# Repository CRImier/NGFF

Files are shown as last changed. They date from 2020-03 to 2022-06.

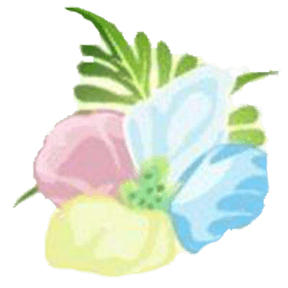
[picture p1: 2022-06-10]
docs/qitas.png

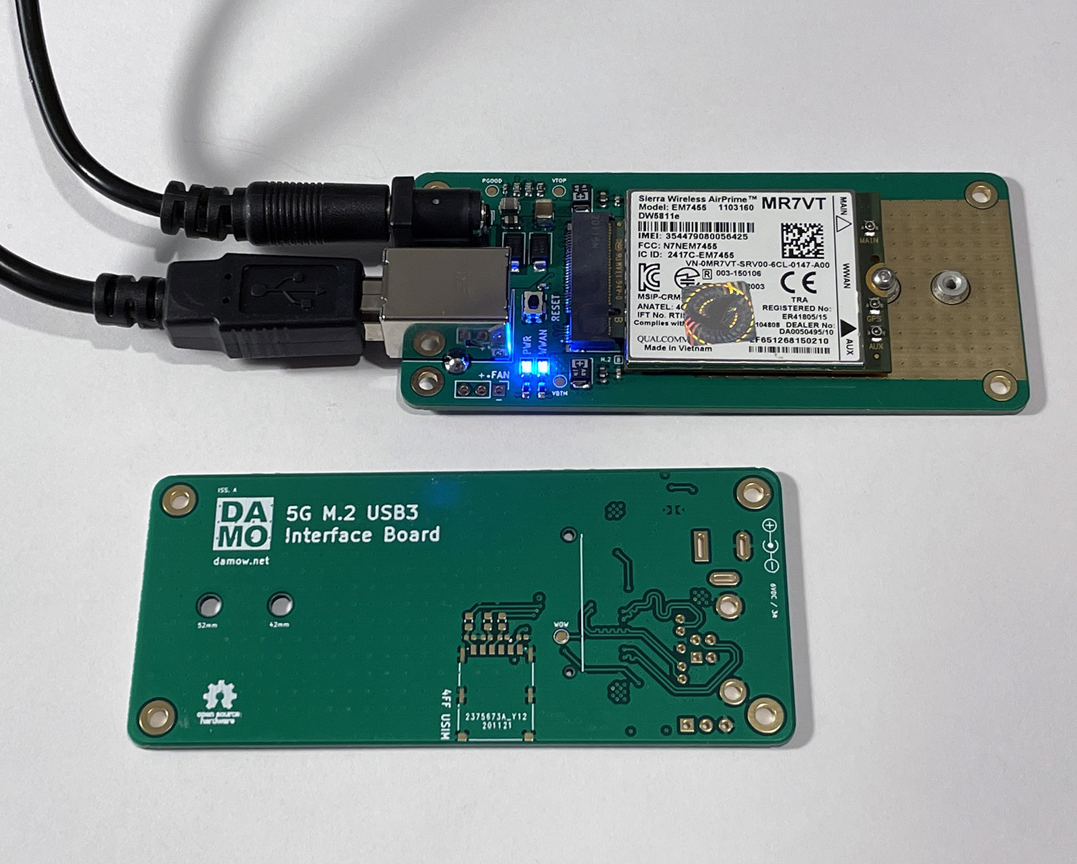
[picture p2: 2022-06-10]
project/images/board-top-bottom.jpg

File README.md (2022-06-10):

# [NGFF](https://github.com/sto-pi/NGFF)

sites (https://www.stops.top)



### [NGFF简介](https://github.com/sto-pi/NGFF)

[NGFF](https://github.com/sto-pi/NGFF) (Next Generation Form Factor)，与 NGFF 并列的是 2.5"（2.5”硬盘（包括HDD和SSD）厚度一般为9.5mm和7mm），NGFF现在已经改名为M.2，M.2有SATA 和PCIe两种总线标准。

M.2接口是一种新的主机接口方案，可以兼容多种通信协议，如sata、PCIe、USB、HSIC、UART、SMBus等。

M.2接口是为超极本（Ultrabook）量身定做的新一代接口标准，以取代原来的mSATA接口。无论是更小巧的规格尺寸，还是更高的传输性能，M.2都远胜于mSATA。

M.2接口，是Intel推出的一种替代MSATA新的接口规范。其实，对于桌面台式机用户来讲，SATA接口已经足以满足大部分用户的需求了，不过考虑到超极本用户的存储需求，Intel才急切的推出了这种新的接口标准。所以，我们在华硕、技嘉、微星等发布的新的9系列主板上都看到了这种新的M.2接口，现已普及。 [1]
与MSATA相比，M.2主要有两个方面的优势。第一是速度方面的优势。M.2接口有两种类型：Socket 2（B key——ngff）和Socket 3（M key——nvme），其中Socket2支持SATA、PCI-E X2接口，而如果采用PCI-E ×2接口标准，最大的读取速度可以达到700MB/s，写入也能达到550MB/s。而其中的Socket 3可支持PCI-E ×4接口，理论带宽可达4GB/s。

第二个是体积方面的优势。虽然，MSATA的固态硬盘体积已经足够小了，但相比M.2接口的固态硬盘，MSATA仍然没有任何优势可言。M.2标准的SSD同mSATA一样可以进行单面NAND闪存颗粒的布置，也可以进行双面布置，其中单面布置的总厚度仅有2.75mm，而双面布置的厚度也仅为3.85mm。而mSATA在体积上的劣势就明显的多，51mm×30mm的尺寸让mSATA在面积上不占优势，而4.85mm的单面布置厚度跟M.2比起来也显得厚了太多。另外，即使在大小相同的情况下，M.2也可以提供更高的存储容量。

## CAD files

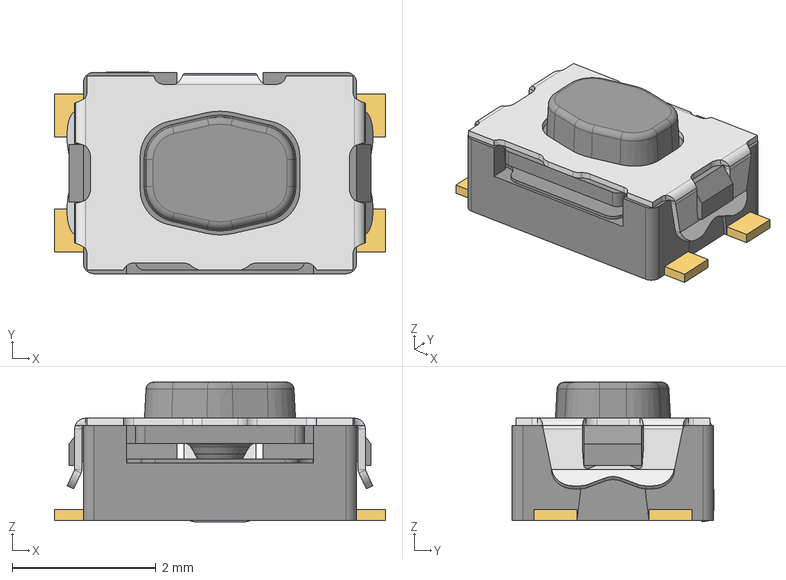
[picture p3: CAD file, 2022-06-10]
project/3d/C&K_-_KMR221GLFS.step
4.60 x 2.80 x 1.94 mm

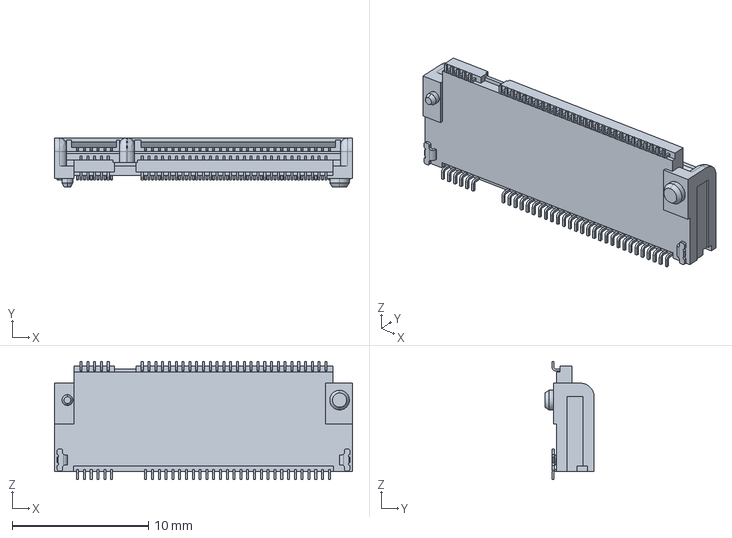
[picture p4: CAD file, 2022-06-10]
project/3d/c-2199119-3-c-3d.stp
21.9 x 3.62 x 8.70 mm

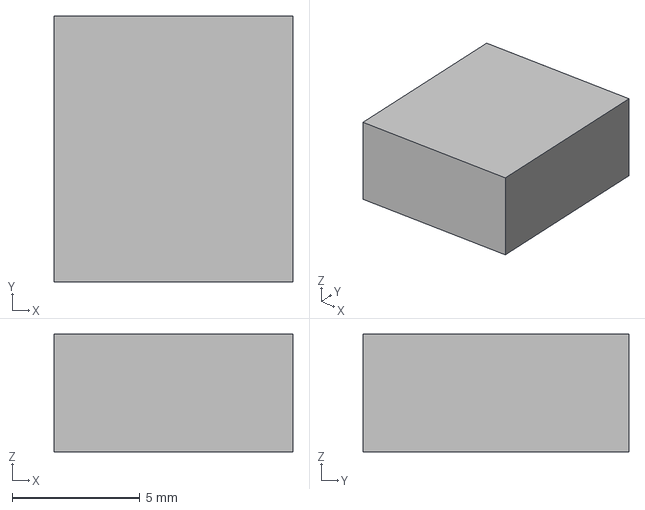
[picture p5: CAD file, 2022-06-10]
project/3d/STMicroelectronics_-_LD1085D2T33R.step
9.35 x 10.4 x 4.60 mm

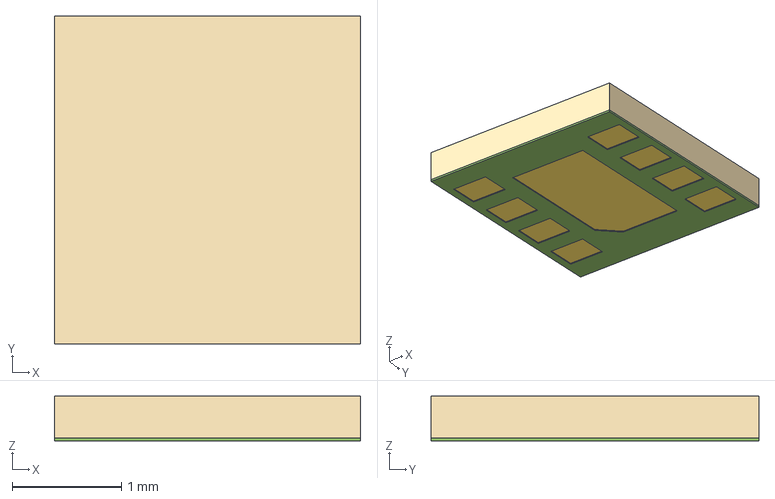
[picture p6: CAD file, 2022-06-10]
project/3d/Texas_Instruments_-_TPS82130SILR.step
2.80 x 3.00 x 0.41 mm

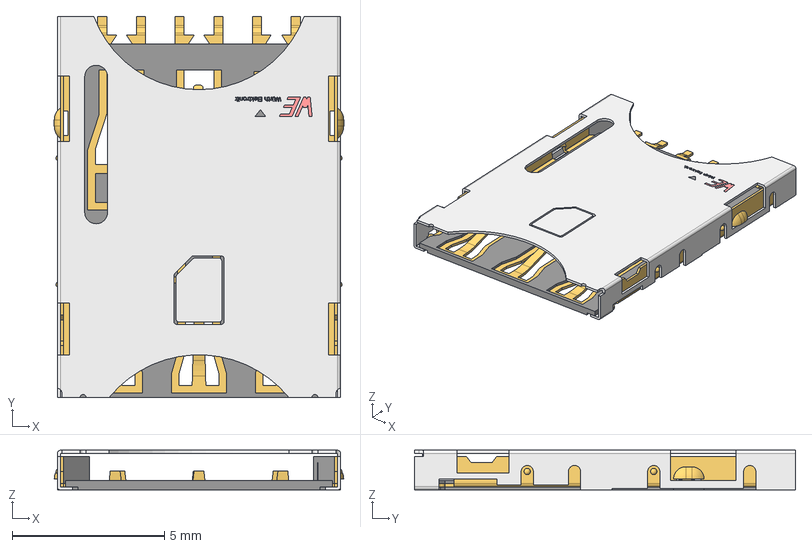
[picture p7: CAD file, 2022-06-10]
project/3d/Wurth_-_693043020611.step
9.50 x 12.5 x 1.30 mm

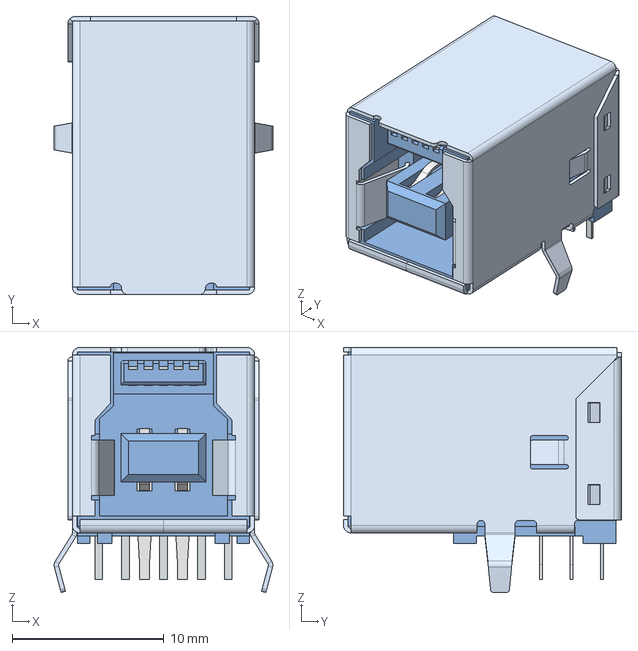
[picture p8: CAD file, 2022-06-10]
project/3d/Wurth_-_692221030100.step
14.4 x 18.3 x 16.1 mm

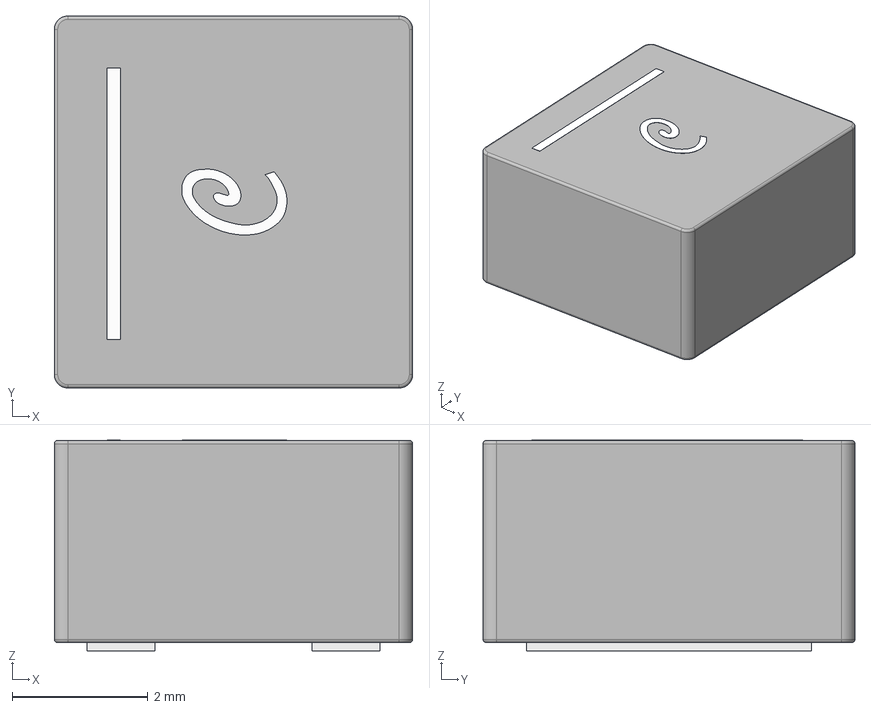
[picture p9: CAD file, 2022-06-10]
project/3d/Coilcraft_-_XAL5030-222MEB.step
5.28 x 5.48 x 3.10 mm
terminals
logo

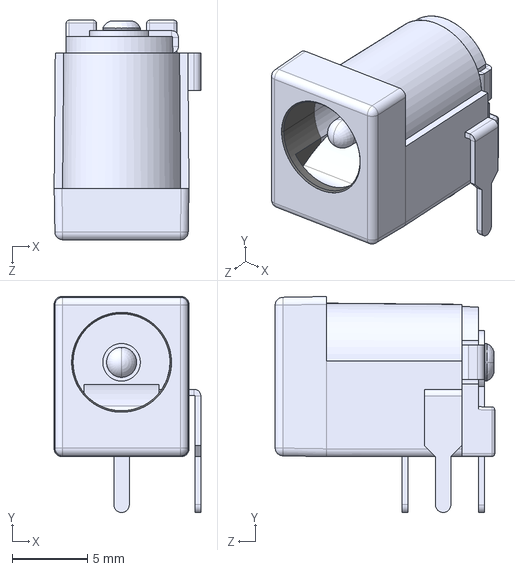
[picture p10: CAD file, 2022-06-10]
project/3d/DC Power Jack 5.5mm x 2.1mm.IGS
9.77 x 14.4 x 14.6 mm

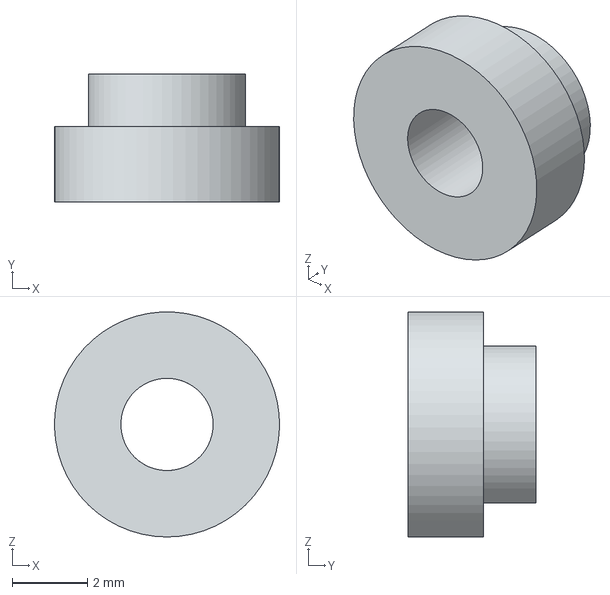
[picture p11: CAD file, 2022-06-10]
project/3d/9774020360R-Standoff.stp
6.00 x 3.40 x 6.00 mm

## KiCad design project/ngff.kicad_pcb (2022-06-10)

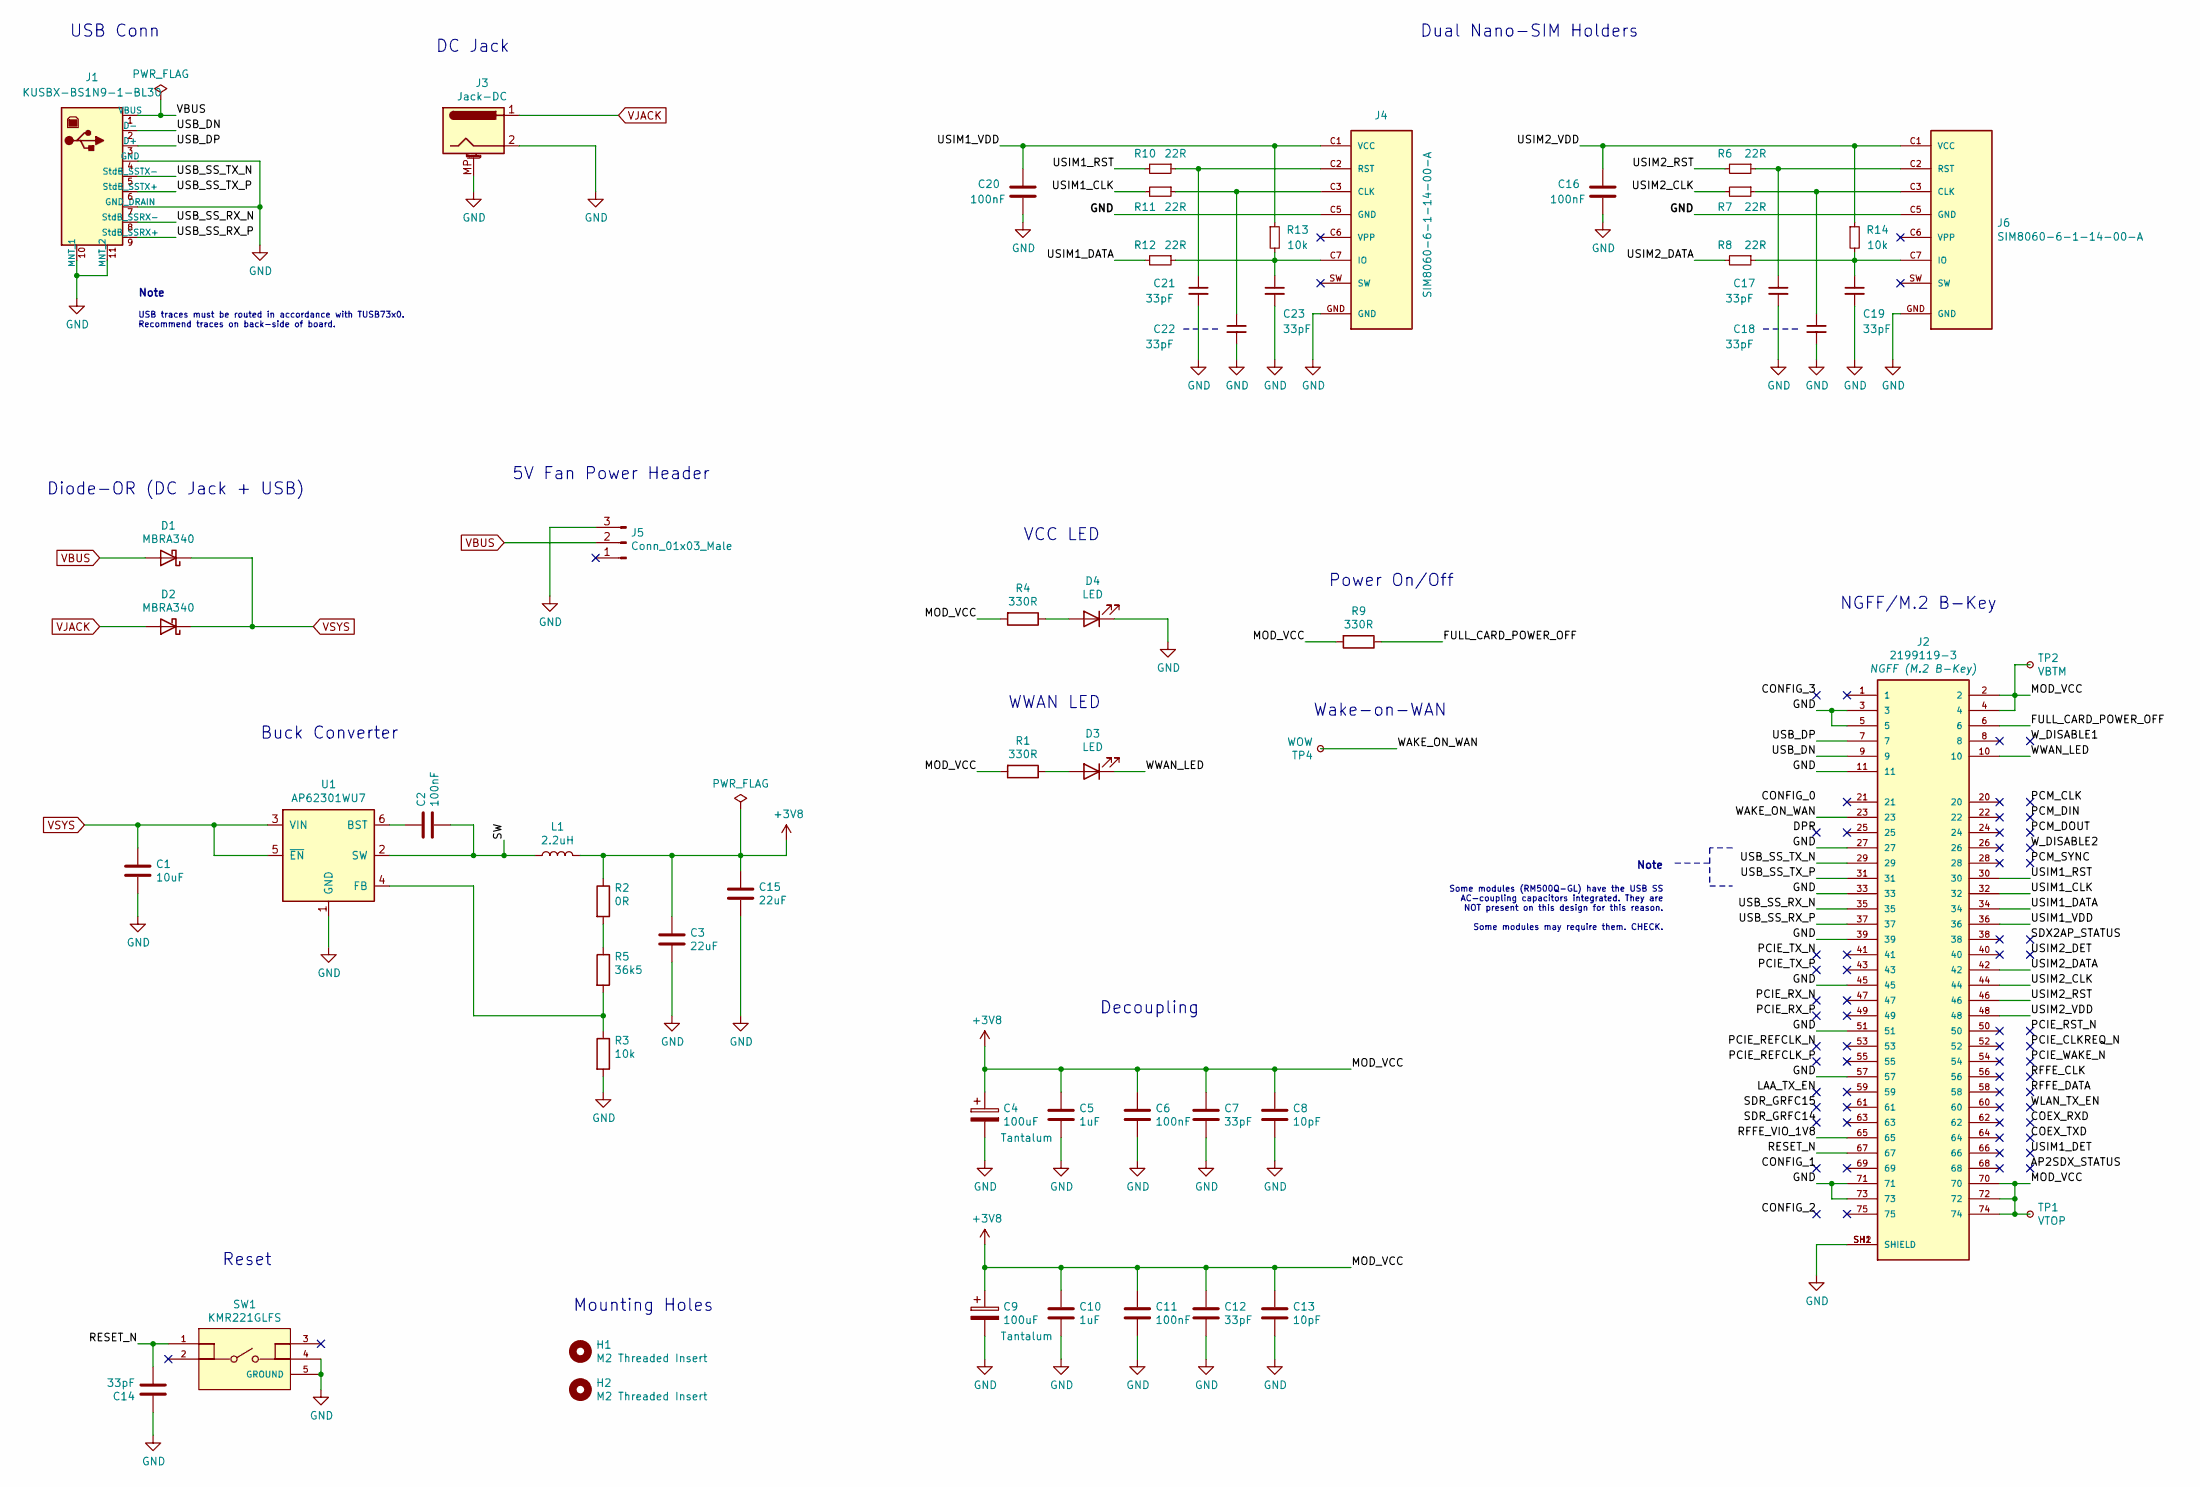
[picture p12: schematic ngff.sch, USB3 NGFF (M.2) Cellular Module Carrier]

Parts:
C1: 10uF; C_0805_2012Metric; MPN GRM21BR71A106KA73K
C2, C6, C11, C16, C20: 100nF; C_0603_1608Metric; MPN C0603C104K3RAC
C3, C15: 22uF; C_1210_3225Metric; MPN CL32B226MOJNNNE
C4, C9: 100uF; CP_EIA-3528-21_Kemet-B; MPN TCJB107M006R0040
C5, C10: 1uF; C_0603_1608Metric; MPN CGA3E1X7R1C105K080AC
C7, C12, C14, C17, C18, C19, C21, C22, C23: 33pF; C_0603_1608Metric; MPN 06035A330KAT2A
C8, C13: 10pF; C_0603_1608Metric; MPN 06035A100JAT4A
D1, D2: MBRA340; D_SMA; MPN MBRA340T3G
D3, D4: LED; LED_0805_2012Metric; MPN APTD2012LQBC/D
H1, H2: M2 Threaded Insert; 9774015243RStandoff; MPN 9774015243R
J1: KUSBX-BS1N9-1-BL30; Wurth-692221030100-0-0-MFG; MPN KUSBX-BS1N9-1-BL30
J2: 2199119-3; TE_2199119-3; MPN 2199119-3
J3: Jack-DC; BarrelJack_Wuerth_6941xx301002; MPN 694106301002
J4, J6: SIM8060-6-1-14-00-A; GCT_SIM8060-6-1-14-00-A; MPN SIM8060-6-1-14-00-A
J5: Conn_01x03_Male; PinHeader_1x03_P2.54mm_Vertical
L1: 2.2uH; L_Coilcraft_XAL5030; MPN XAL5030-222MEC
R1, R4, R9: 330R; R_0603_1608Metric
R2: 0R; R_0603_1608Metric
R3, R13, R14: 10k; R_0603_1608Metric
R5: 36k5; R_0603_1608Metric; MPN CRCW060336K5FKEA
R6, R7, R8, R10, R11, R12: 22R; R_0603_1608Metric
SW1: KMR221GLFS; CK-KMR221GLFS-MFG; MPN KMR221GLFS
TP1: VTOP; TestPoint_Pad_D1.5mm
TP2: VBTM; TestPoint_Pad_D1.5mm
TP4: WOW; TestPoint_Pad_D1.5mm
U1: AP62301WU7; TSOT-23-6; MPN AP62301WU-7

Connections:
+3V8: C3.1, C4.1, C5.1, C6.1, C7.1, C8.1, C9.1, C10.1, C11.1, C12.1, C13.1, C15.1, J2.2, J2.4, J2.70, J2.72, J2.74, L1.2, R1.2, R2.1, R4.2, R9.2, TP1.1, TP2.1
/FULL_CARD_POWER_OFF: J2.6, R9.1
/RESET_N: C14.2, J2.67, SW1.1
/RFFE_VIO_1V8: J2.65
/SW: C2.2, L1.1, U1.2 (SW)
/USB_DN: J1.2 (D-), J2.9
/USB_DP: J1.3 (D+), J2.7
/USB_SS_RX_N: J1.8 (StdB_SSRX-), J2.35
/USB_SS_RX_P: J1.9 (StdB_SSRX+), J2.37
/USB_SS_TX_N: J1.5 (StdB_SSTX-), J2.29
/USB_SS_TX_P: J1.6 (StdB_SSTX+), J2.31
/USIM1_CLK: J2.32, R11.2
/USIM1_DATA: J2.34, R12.2
/USIM1_RST: J2.30, R10.2
/USIM1_VDD: C20.1, J2.36, J4.C1 (VCC), R13.1
/USIM2_CLK: J2.44, R7.2
/USIM2_DATA: J2.42, R8.2
/USIM2_RST: J2.46, R6.2
/USIM2_VDD: C16.1, J2.48, J6.C1 (VCC), R14.1
/WAKE_ON_WAN: J2.23, TP4.1
/WWAN_LED: D3.1 (K), J2.10
GND: C1.2, C3.2, C4.2, C5.2, C6.2, C7.2, C8.2, C9.2, C10.2, C11.2, C12.2, C13.2, C14.1, C15.2, C16.2, C17.2, C18.2, C19.2, C20.2, C21.2, C22.2, C23.2, D4.1 (K), J1.4 (GND), J1.7 (GND_DRAIN), J1.10 (MNT_1), J1.11 (MNT_2), J2.3, J2.5, J2.11, J2.27, J2.33, J2.39, J2.45, J2.51, J2.57, J2.71, J2.73, J2.SH1 (SHIELD), J2.SH2 (SHIELD), J3.2, J3.MP (MountPin), J4.C5 (GND), J4.GND, J5.3, J6.C5 (GND), J6.GND, R3.2, SW1.4, SW1.5 (GROUND), U1.1 (GND)
unnamed: C2.1, U1.6 (BST)
unnamed: C17.1, J6.C2 (RST), R6.1
unnamed: C18.1, J6.C3 (CLK), R7.1
unnamed: C19.1, J6.C7 (IO), R8.1, R14.2
unnamed: C21.1, J4.C2 (RST), R10.1
unnamed: C22.1, J4.C3 (CLK), R11.1
unnamed: C23.1, J4.C7 (IO), R12.1, R13.2
unnamed: D3.2 (A), R1.1
unnamed: D4.2 (A), R4.1
unnamed: R2.2, R5.1
unnamed: R3.1, R5.2, U1.4 (FB)
VBUS: D1.2 (A), J1.1 (VBUS), J5.2
VJACK: D2.2 (A), J3.1
VSYS: C1.1, D1.1 (K), D2.1 (K), U1.3 (VIN), U1.5 (~EN)

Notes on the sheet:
Dual Nano-SIM Holders
VCC LED
WWAN LED
Reset
5V Fan Power Header
Diode-OR (DC Jack + USB)
USB Conn
DC Jack
Power On/Off
Decoupling
NGFF/M.2 B-Key
Wake-on-WAN
Mounting Holes
Note
Some modules (RM500Q-GL) have the USB SS AC-coupling capacitors integrated. They are NOT present on this design for this reason. Some modules may require them. CHECK.
USB traces must be routed in accordance with TUSB73x0. Recommend traces on back-side of board.
Buck Converter

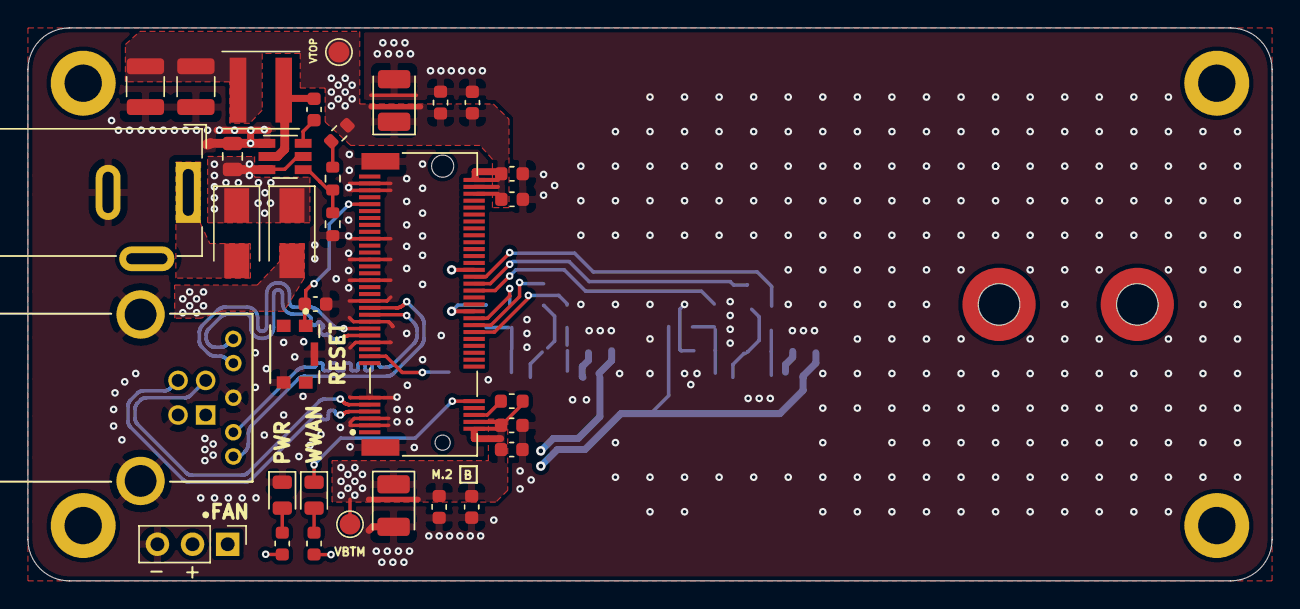
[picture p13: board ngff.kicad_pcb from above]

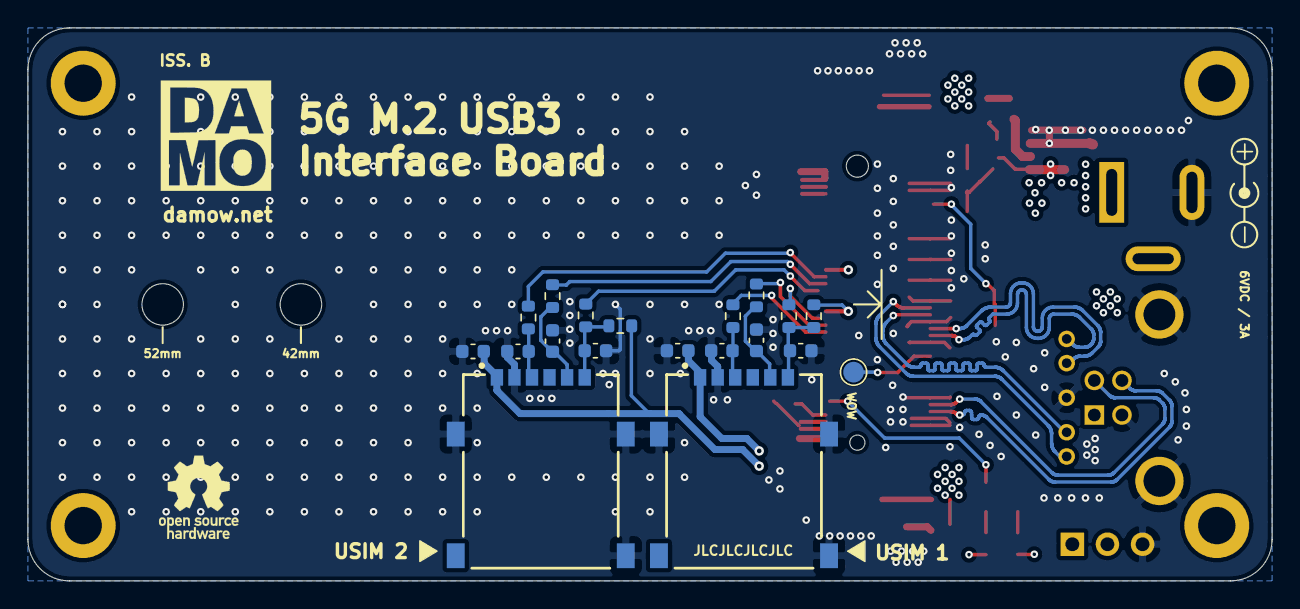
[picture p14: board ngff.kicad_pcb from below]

Board: 4 copper layers, 90.0 x 40.0 mm, 55 parts (19 on the bottom side), 35 nets.

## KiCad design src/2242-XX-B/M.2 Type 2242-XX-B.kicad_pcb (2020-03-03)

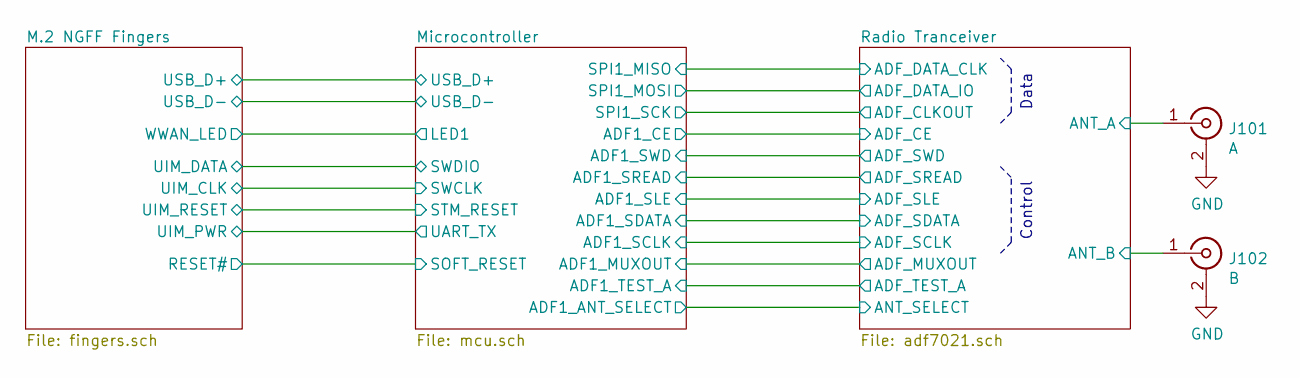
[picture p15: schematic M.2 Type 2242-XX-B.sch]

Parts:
J101: A; U.FL_Hirose_U.FL-R-SMT-1_Vertical
J102: B; U.FL_Hirose_U.FL-R-SMT-1_Vertical

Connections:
/Radio Tranceiver/ANT_A: J101.1 (In); also elsewhere on the board
/Radio Tranceiver/ANT_B: J102.1 (In); also elsewhere on the board
GND: J101.2 (Ext), J102.2 (Ext); also elsewhere on the board

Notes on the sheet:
Control
Data

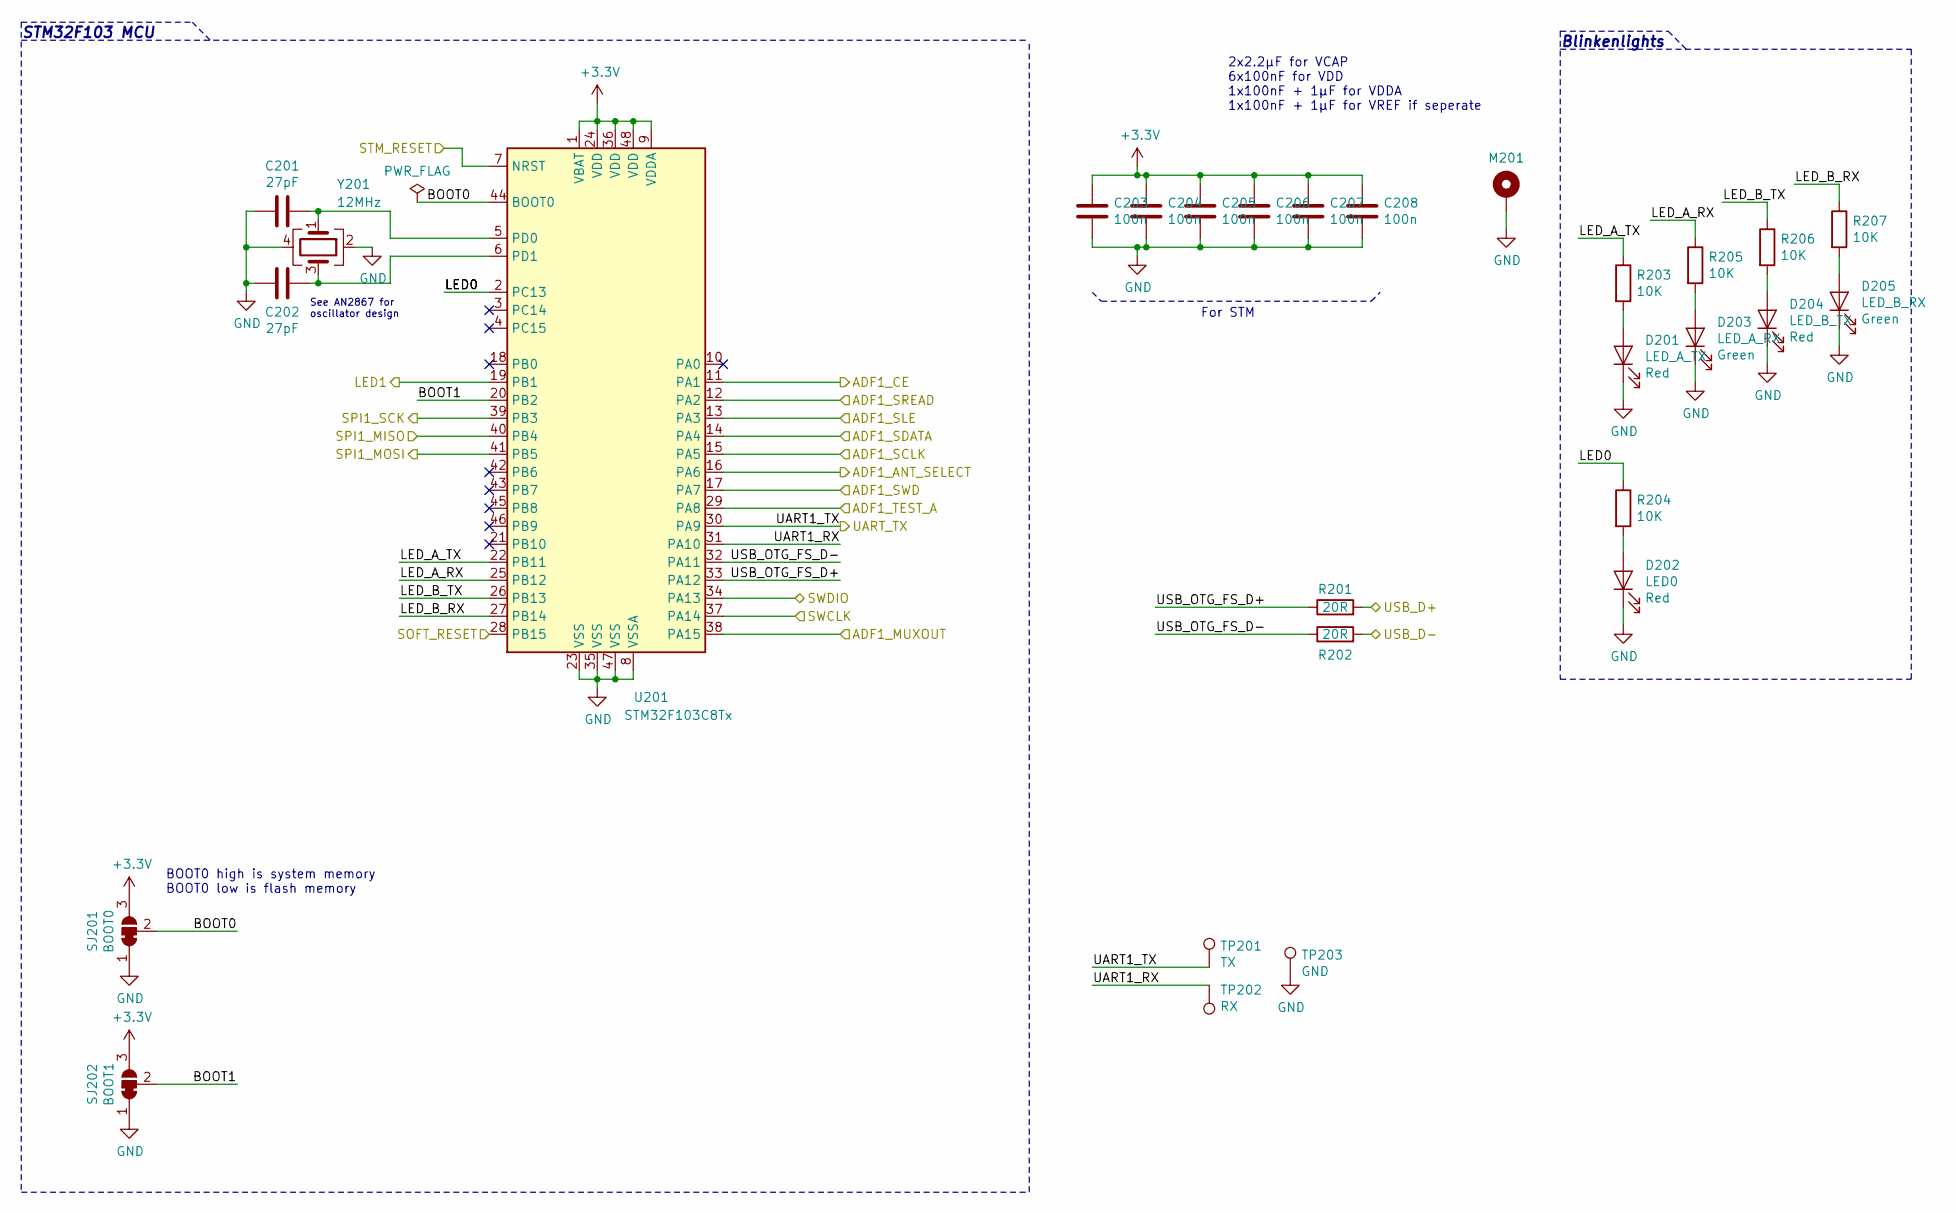
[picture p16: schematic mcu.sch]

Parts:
C201, C202: 27pF; C_0603_1608Metric
C203, C204, C205, C206, C207, C208: 100n; C_0603_1608Metric
D201: LED_A_TX; LED_0603_1608Metric
D202: LED0; LED_0603_1608Metric
D203: LED_A_RX; LED_0603_1608Metric
D204: LED_B_TX; LED_0603_1608Metric
D205: LED_B_RX; LED_0603_1608Metric
M201: MountingHole_Pad; M.2_Standoff_Card_Pad
R201, R202: 20R; R_0603_1608Metric
R203, R204, R205, R206, R207: 10K; R_0603_1608Metric
SJ201: BOOT0; SolderJumper-3_P1.3mm_Bridged12_RoundedPad1.0x1.5mm
SJ202: BOOT1; SolderJumper-3_P1.3mm_Bridged12_RoundedPad1.0x1.5mm
TP201: TX; TestPad
TP202: RX; TestPad
TP203: GND; TestPad
U201: STM32F103C8Tx; LQFP-48_7x7mm_P0.5mm
Y201: 12MHz; Crystal_SMD_3225-4Pin_3.2x2.5mm; digikey# 1923-1568-1-ND

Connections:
+3V3: C203.1, C204.1, C205.1, C206.1, C207.1, C208.1, SJ201.3 (B), SJ202.3 (B), U201.1 (VBAT), U201.9 (VDDA), U201.24 (VDD), U201.36 (VDD), U201.48 (VDD); also elsewhere on the board
/M.2 NGFF Fingers/RESET#: U201.28 (PB15); also elsewhere on the board
/M.2 NGFF Fingers/USB_D+: R201.2; also elsewhere on the board
/M.2 NGFF Fingers/USB_D-: R202.2; also elsewhere on the board
/Microcontroller/ADF1_ANT_SELECT: U201.16 (PA6); also elsewhere on the board
/Microcontroller/ADF1_CE: U201.11 (PA1); also elsewhere on the board
/Microcontroller/ADF1_MUXOUT: U201.38 (PA15); also elsewhere on the board
/Microcontroller/ADF1_SCLK: U201.15 (PA5); also elsewhere on the board
/Microcontroller/ADF1_SDATA: U201.14 (PA4); also elsewhere on the board
/Microcontroller/ADF1_SLE: U201.13 (PA3); also elsewhere on the board
/Microcontroller/ADF1_SREAD: U201.12 (PA2); also elsewhere on the board
/Microcontroller/ADF1_SWD: U201.17 (PA7); also elsewhere on the board
/Microcontroller/ADF1_TEST_A: U201.29 (PA8); also elsewhere on the board
/Microcontroller/BOOT0: SJ201.2 (C), U201.44 (BOOT0)
/Microcontroller/BOOT1: SJ202.2 (C), U201.20 (PB2)
/Microcontroller/LED0: R204.1, U201.2 (PC13)
/Microcontroller/LED1: U201.19 (PB1); also elsewhere on the board
/Microcontroller/LED_A_RX: R205.1, U201.25 (PB12)
/Microcontroller/LED_A_TX: R203.1, U201.22 (PB11)
/Microcontroller/LED_B_RX: R207.1, U201.27 (PB14)
/Microcontroller/LED_B_TX: R206.1, U201.26 (PB13)
/Microcontroller/STM_RESET: U201.7 (NRST); also elsewhere on the board
/Microcontroller/SWCLK: U201.37 (PA14); also elsewhere on the board
/Microcontroller/SWDIO: U201.34 (PA13); also elsewhere on the board
/Microcontroller/UART1_RX: TP202.1, U201.31 (PA10)
/Microcontroller/UART_TX: TP201.1, U201.30 (PA9); also elsewhere on the board
/Microcontroller/USB_OTG_FS_D+: R201.1, U201.33 (PA12)
/Microcontroller/USB_OTG_FS_D-: R202.1, U201.32 (PA11)
/Radio Tranceiver/ADF_CLKOUT: U201.39 (PB3); also elsewhere on the board
/Radio Tranceiver/ADF_DATA_CLK: U201.40 (PB4); also elsewhere on the board
/Radio Tranceiver/ADF_DATA_IO: U201.41 (PB5); also elsewhere on the board
GND: C201.2, C202.2, C203.2, C204.2, C205.2, C206.2, C207.2, C208.2, D201.1 (K), D202.1 (K), D203.1 (K), D204.1 (K), D205.1 (K), M201.1, SJ201.1 (A), SJ202.1 (A), TP203.1, U201.8 (VSSA), U201.23 (VSS), U201.35 (VSS), U201.47 (VSS), Y201.2, Y201.4; also elsewhere on the board
unnamed: C201.1, U201.5 (PD0), Y201.1
unnamed: C202.1, U201.6 (PD1), Y201.3
unnamed: D201.2 (A), R203.2
unnamed: D202.2 (A), R204.2
unnamed: D203.2 (A), R205.2
unnamed: D204.2 (A), R206.2
unnamed: D205.2 (A), R207.2

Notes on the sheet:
See AN2867 for oscillator design
STM32F103 MCU
Blinkenlights
2x2.2µF for VCAP 6x100nF for VDD 1x100nF + 1µF for VDDA 1x100nF + 1µF for VREF if seperate
For STM
BOOT0 high is system memory BOOT0 low is flash memory

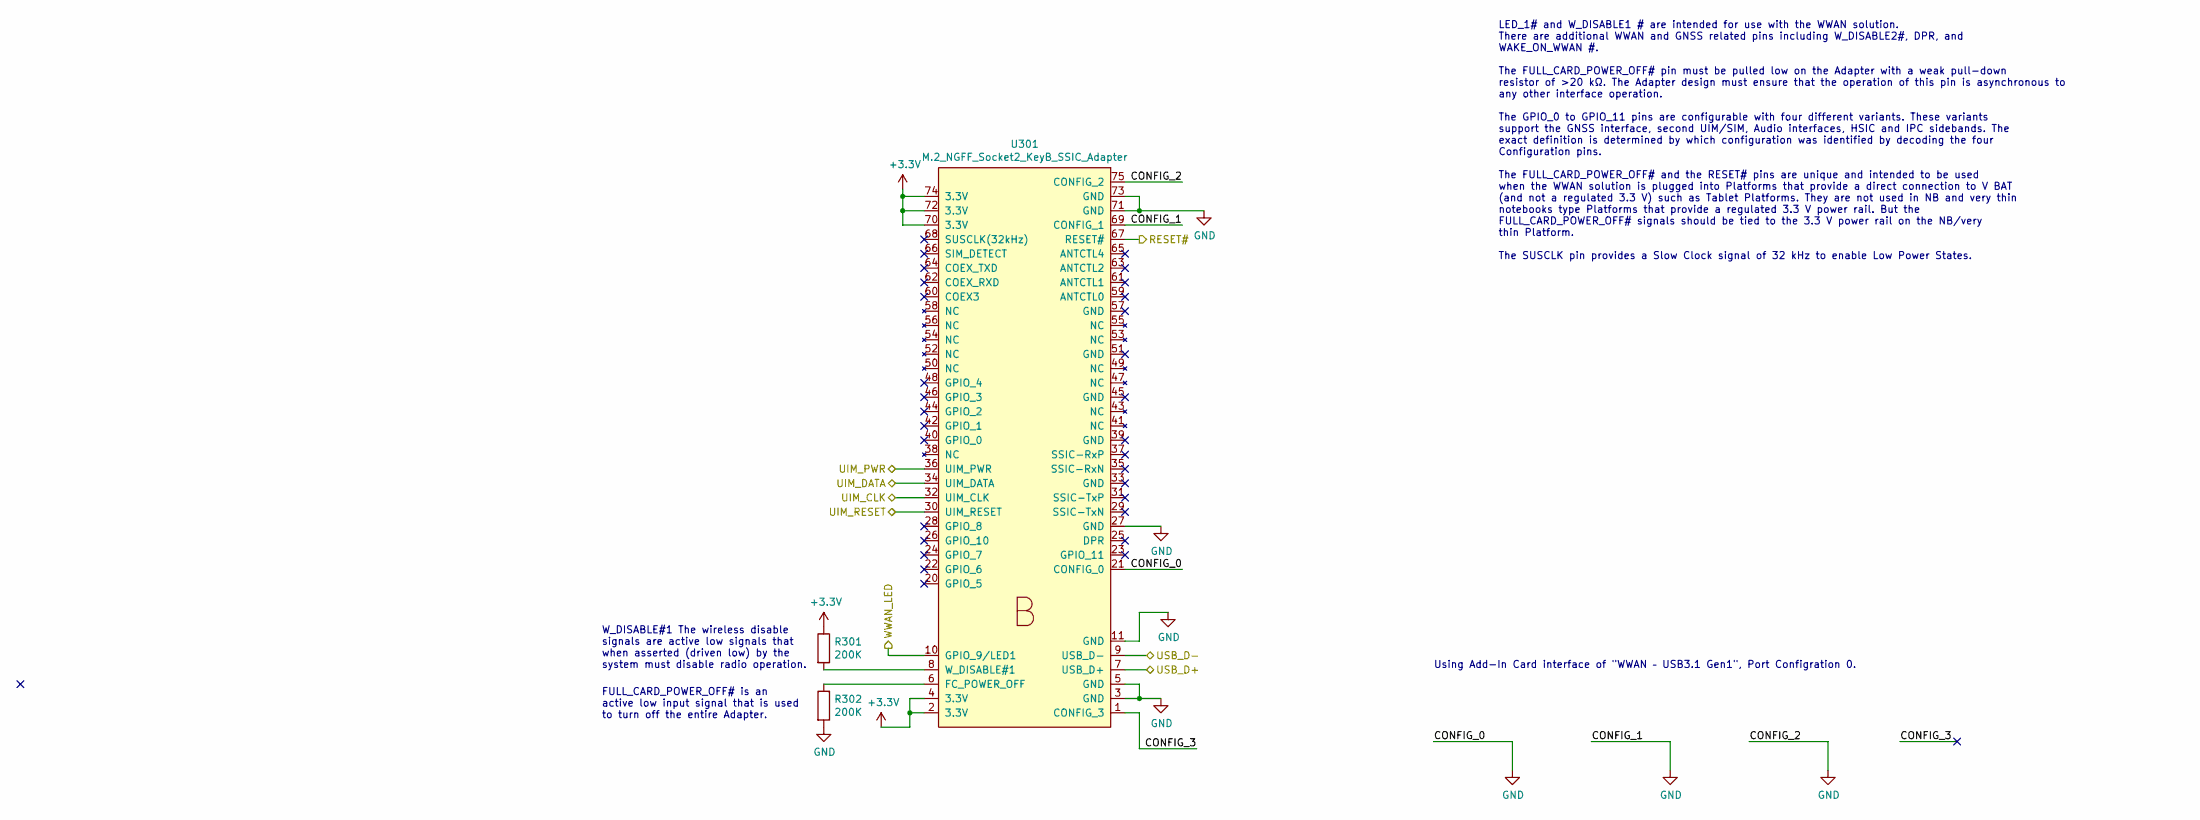
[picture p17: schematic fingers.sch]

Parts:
R301, R302: 200K; R_0603_1608Metric
U301: M.2_NGFF_Socket2_KeyB_SSIC_Adapter; M.2_Key_B_Fingers

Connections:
+3V3: R301.1, U301.2 (3.3V), U301.4 (3.3V), U301.70 (3.3V), U301.72 (3.3V), U301.74 (3.3V); also elsewhere on the board
/M.2 NGFF Fingers/CONFIG_3: U301.1 (CONFIG_3)
/M.2 NGFF Fingers/RESET#: U301.67 (RESET#); also elsewhere on the board
/M.2 NGFF Fingers/USB_D+: U301.7 (USB_D+); also elsewhere on the board
/M.2 NGFF Fingers/USB_D-: U301.9 (USB_D-); also elsewhere on the board
/Microcontroller/LED1: U301.10 (GPIO_9/LED1); also elsewhere on the board
/Microcontroller/STM_RESET: U301.30 (UIM_RESET); also elsewhere on the board
/Microcontroller/SWCLK: U301.32 (UIM_CLK); also elsewhere on the board
/Microcontroller/SWDIO: U301.34 (UIM_DATA); also elsewhere on the board
/Microcontroller/UART_TX: U301.36 (UIM_PWR); also elsewhere on the board
GND: R302.2, U301.3 (GND), U301.5 (GND), U301.11 (GND), U301.21 (CONFIG_0), U301.27 (GND), U301.69 (CONFIG_1), U301.71 (GND), U301.73 (GND), U301.75 (CONFIG_2); also elsewhere on the board
unnamed: R301.2, U301.8 (W_DISABLE#1)
unnamed: R302.1, U301.6 (FC_POWER_OFF)

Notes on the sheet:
LED_1# and W_DISABLE1 # are intended for use with the WWAN solution. There are additional WWAN and GNSS related pins including W_DISABLE2#, DPR, and WAKE_ON_WWAN #. The FULL_CARD_POWER_OFF# pin must be pulled low on the Adapter with a weak pull-down resistor of >20 kΩ. The Adapter design must ensur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
FULL_CARD_POWER_OFF# is an active low input signal that is used to turn off the entire Adapter.
W_DISABLE#1 The wireless disable signals are active low signals that when asserted (driven low) by the system must disable radio operation.
Using Add-In Card interface of "WWAN – USB3.1 Gen1", Port Configration 0.

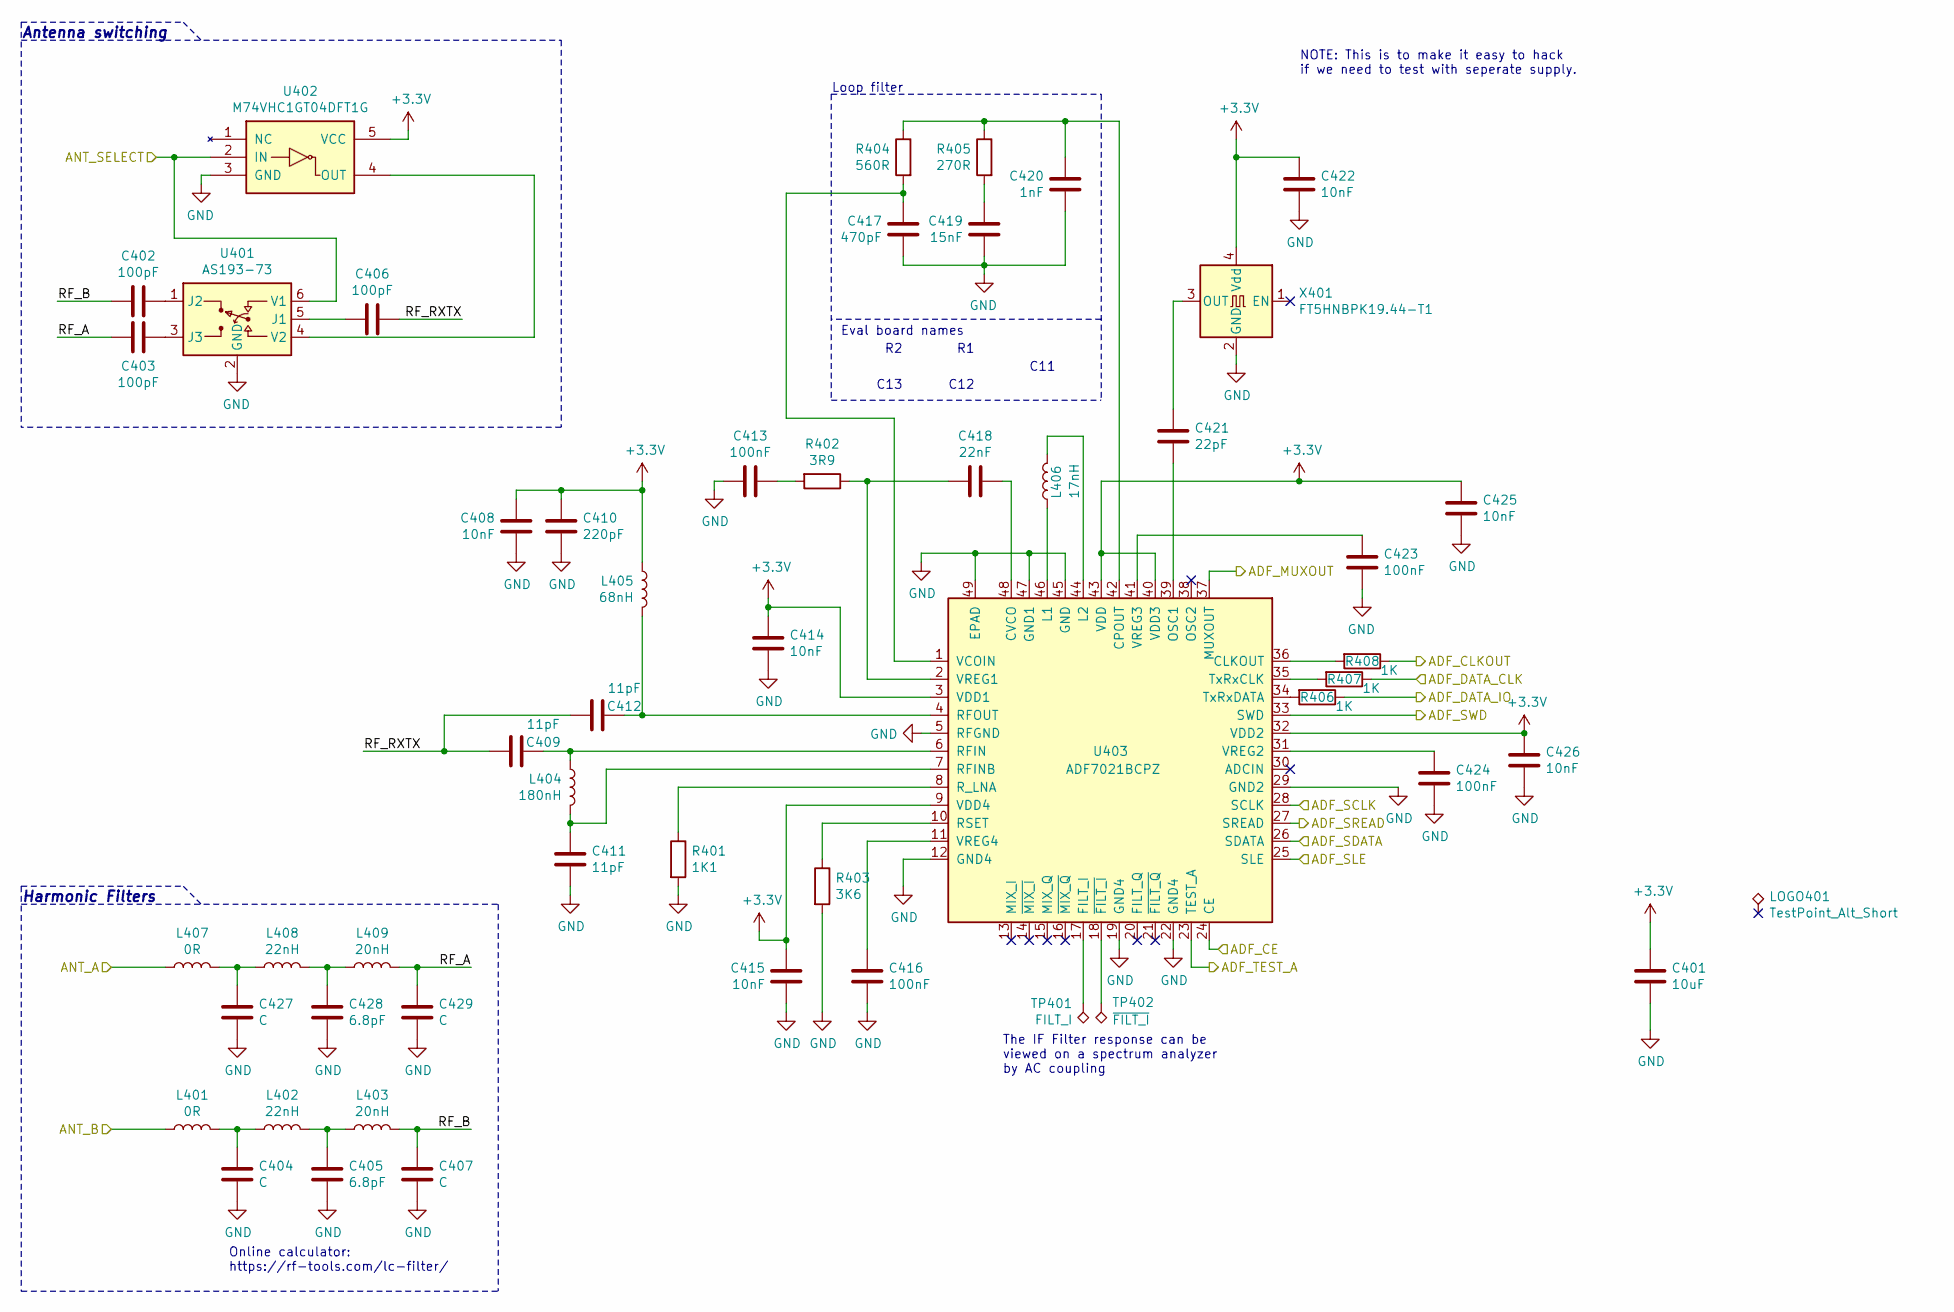
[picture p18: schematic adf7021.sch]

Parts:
C401: 10uF; C_0805_2012Metric
C402, C403, C406: 100pF; C_0603_1608Metric
C404, C407, C427, C429: C; C_0603_1608Metric
C405, C428: 6.8pF; C_0603_1608Metric
C408, C414, C415, C422, C425, C426: 10nF; C_0603_1608Metric
C409, C411, C412: 11pF; C_0603_1608Metric
C410: 220pF; C_0603_1608Metric
C413, C416, C423, C424: 100nF; C_0603_1608Metric
C417: 470pF; C_0603_1608Metric
C418: 22nF; C_0603_1608Metric
C419: 15nF; C_0603_1608Metric
C420: 1nF; C_0603_1608Metric
C421: 22pF; C_0603_1608Metric
L401, L407: 0R; L_0603_1608Metric
L402, L408: 22nH; L_0603_1608Metric
L403, L409: 20nH; L_0603_1608Metric
L404: 180nH; L_0603_1608Metric
L405: 68nH; L_0603_1608Metric
L406: 17nH; L_0603_1608Metric
LOGO401: TestPoint_Alt_Short; KiCad-Logo_Back
R401: 1K1; R_0603_1608Metric
R402: 3R9; R_0603_1608Metric
R403: 3K6; R_0603_1608Metric
R404: 560R; R_0603_1608Metric
R405: 270R; R_0603_1608Metric
R406, R407, R408: 1K; R_0603_1608Metric
TP401: FILT_I; TestPad
TP402: ~FILT_I; TestPad
U401: AS193-73; SuperSOT-6
U402: M74VHC1GT04DFT1G; SOT-353_SC-70-5; digikey# M74VHC1GT04DFT1GOSCT-ND
U403: ADF7021BCPZ; LFCSP-48-1EP_7x7mm_P0.5mm_EP4.1x4.1mm_ThermalVias
X401: FT5HNBPK19.44-T1; FOX924; digikey# 631-1072-1-ND

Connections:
+3V3: C401.1, C408.1, C410.1, C414.1, C415.1, C422.1, C425.1, C426.1, L405.1, U402.5 (VCC), U403.3 (VDD1), U403.9 (VDD4), U403.32 (VDD2), U403.40 (VDD3), U403.43 (VDD), X401.4 (Vdd); also elsewhere on the board
/Microcontroller/ADF1_ANT_SELECT: U401.6 (V1), U402.2 (IN); also elsewhere on the board
/Microcontroller/ADF1_CE: U403.24 (CE); also elsewhere on the board
/Microcontroller/ADF1_MUXOUT: U403.37 (MUXOUT); also elsewhere on the board
/Microcontroller/ADF1_SCLK: U403.28 (SCLK); also elsewhere on the board
/Microcontroller/ADF1_SDATA: U403.26 (SDATA); also elsewhere on the board
/Microcontroller/ADF1_SLE: U403.25 (SLE); also elsewhere on the board
/Microcontroller/ADF1_SREAD: U403.27 (SREAD); also elsewhere on the board
/Microcontroller/ADF1_SWD: U403.33 (SWD); also elsewhere on the board
/Microcontroller/ADF1_TEST_A: U403.23 (TEST_A); also elsewhere on the board
/Radio Tranceiver/ADF_CLKOUT: R408.1; also elsewhere on the board
/Radio Tranceiver/ADF_DATA_CLK: R407.1; also elsewhere on the board
/Radio Tranceiver/ADF_DATA_IO: R406.1; also elsewhere on the board
/Radio Tranceiver/ANT_A: L407.1; also elsewhere on the board
/Radio Tranceiver/ANT_B: L401.1; also elsewhere on the board
/Radio Tranceiver/RF_A: C403.2, C429.1, L409.2
/Radio Tranceiver/RF_B: C402.2, C407.1, L403.2
/Radio Tranceiver/RF_RXTX: C406.1, C409.1, C412.1
GND: C401.2, C404.2, C405.2, C407.2, C408.2, C410.2, C411.2, C413.2, C414.2, C415.2, C416.2, C417.2, C419.2, C420.2, C422.2, C423.2, C424.2, C425.2, C426.2, C427.2, C428.2, C429.2, R401.2, R403.2, U401.2 (GND), U402.3 (GND), U403.5 (RFGND), U403.12 (GND4), U403.19 (GND4), U403.22 (GND4), U403.29 (GND2), U403.45 (GND), U403.47 (GND1), U403.49 (EPAD), X401.2 (GND); also elsewhere on the board
unnamed: C402.1, U401.1 (J2)
unnamed: C403.1, U401.3 (J3)
unnamed: C404.1, L401.2, L402.1
unnamed: C405.1, L402.2, L403.1
unnamed: C406.2, U401.5 (J1)
unnamed: C409.2, L404.1, U403.6 (RFIN)
unnamed: C411.1, L404.2, U403.7 (RFINB)
unnamed: C412.2, L405.2, U403.4 (RFOUT)
unnamed: C413.1, R402.2
unnamed: C416.1, U403.11 (VREG4)
unnamed: C417.1, R404.2, U403.1 (VCOIN)
unnamed: C418.1, U403.48 (CVCO)
unnamed: C418.2, R402.1, U403.2 (VREG1)
unnamed: C419.1, R405.2
unnamed: C420.1, R404.1, R405.1, U403.42 (CPOUT)
unnamed: C421.1, X401.3 (OUT)
unnamed: C421.2, U403.39 (OSC1)
unnamed: C423.1, U403.41 (VREG3)
unnamed: C424.1, U403.31 (VREG2)
unnamed: C427.1, L407.2, L408.1
unnamed: C428.1, L408.2, L409.1
unnamed: L406.1, U403.46 (L1)
unnamed: L406.2, U403.44 (L2)
unnamed: R401.1, U403.8 (R_LNA)
unnamed: R403.1, U403.10 (RSET)
unnamed: R406.2, U403.34 (TxRxDATA)
unnamed: R407.2, U403.35 (TxRxCLK)
unnamed: R408.2, U403.36 (CLKOUT)
unnamed: TP401.1, U403.17 (FILT_I)
unnamed: TP402.1, U403.18 (~FILT_I)
unnamed: U401.4 (V2), U402.4 (OUT)

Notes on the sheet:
Antenna switching
NOTE: This is to make it easy to hack if we need to test with seperate supply.
The IF Filter response can be viewed on a spectrum analyzer by AC coupling
Loop filter
Eval board names
C13
C12
C11
Online calculator: https://rf-tools.com/lc-filter/
Harmonic Filters

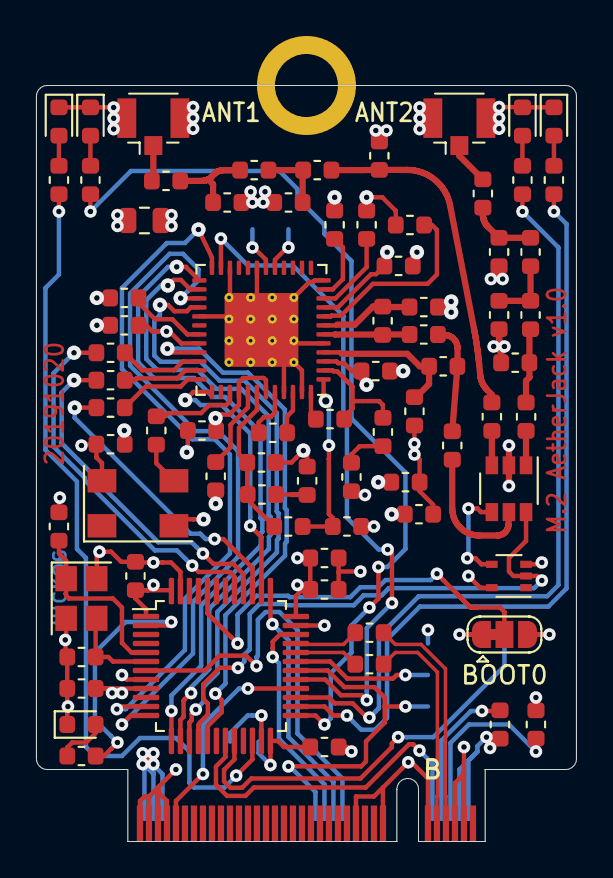
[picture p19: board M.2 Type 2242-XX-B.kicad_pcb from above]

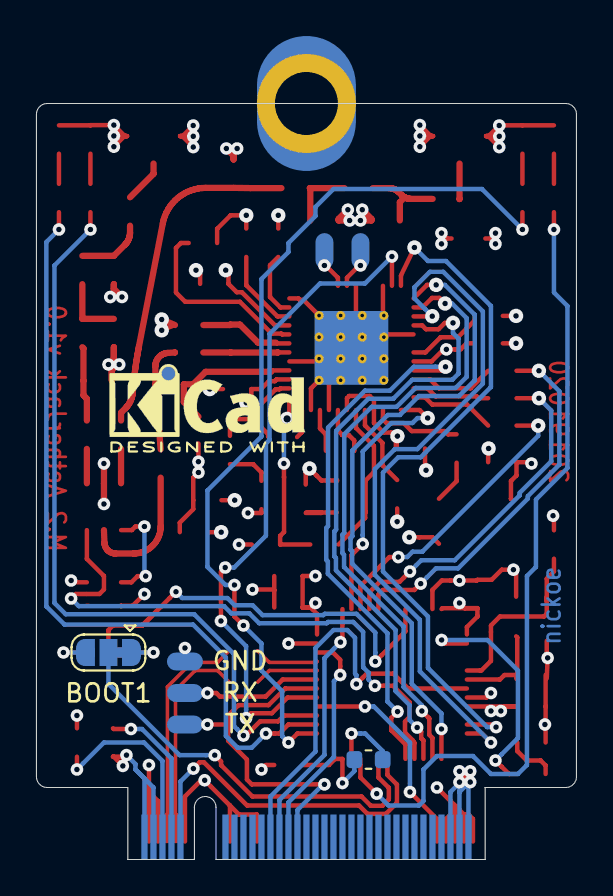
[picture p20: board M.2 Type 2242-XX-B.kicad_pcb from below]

Board: 4 copper layers, 30.0 x 42.0 mm, 86 parts (8 on the bottom side), 77 nets.

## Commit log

2020-03-03 add project
    [m2ngff.kicad_pcb]
2020-03-03 add mcu templetes
    [M.2 Type 2242-XX-B.kicad_pcb, M.2 Type 2242-XX-B.sch, adf7021.sch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]
2021-10-21 Fixed the A+E footprint generation by refactoring bottom horizontal line drawing out of first_key+second_key block into the bottom endpoint processing block, together with soldermask opening calculat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
